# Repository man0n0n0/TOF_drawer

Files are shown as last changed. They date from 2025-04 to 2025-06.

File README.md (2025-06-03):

# configuration mode notice 

- turn off the device by unplugging it
- **keep** the config button pressed
- plug the device
  (while started you can release the button)
- connect on the wifi hotspot
  SSID : **"drawer-config"**
  PASSWORD : **"admin123"**
- while connected go to **192.168.4.1**
- modify values and **Save settings**
- the drawer should automatically restart in "main mode" with updated values

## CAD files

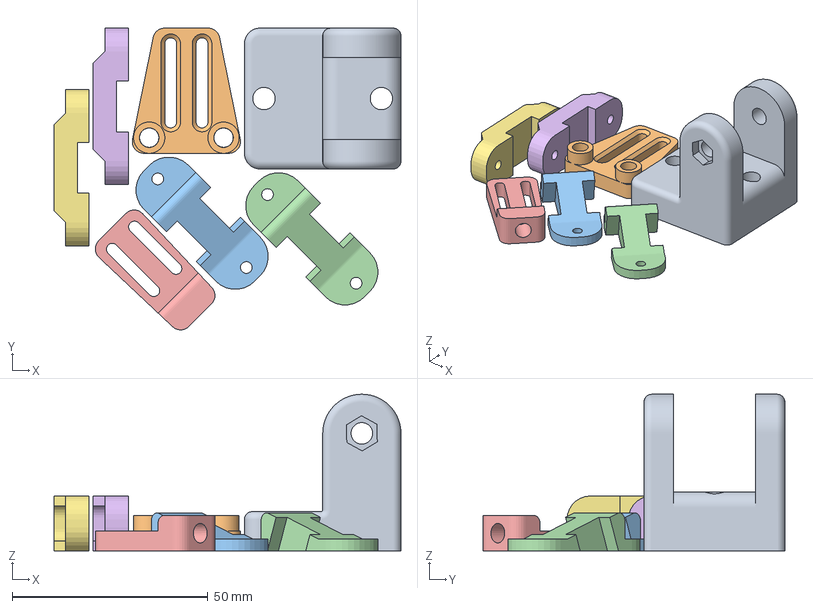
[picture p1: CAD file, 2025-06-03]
hardware/00fullparts.3mf
88.7 x 77.1 x 40.0 mm
04pulley_holder_screw-BodyPocket002.stl
01end_switch-Body.stl
ld2410_angledholder-Body003Chamfer.stl x 2
end_switch_compensator-Body.stl
02GT5belttensionner-Body.stl x 2

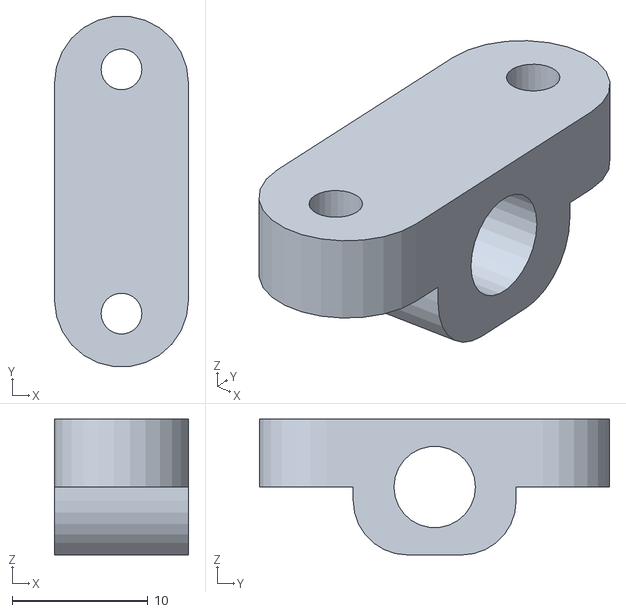
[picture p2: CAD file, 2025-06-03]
hardware/end_switch_compensator-Body.stl
9.86 x 25.8 x 10.0

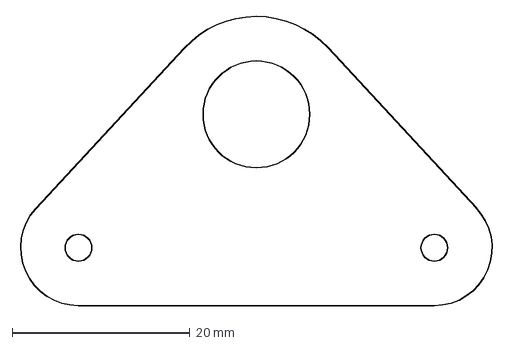
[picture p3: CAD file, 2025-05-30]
hardware/config_swtich_holder.dxf
54.0 x 32.5 mm

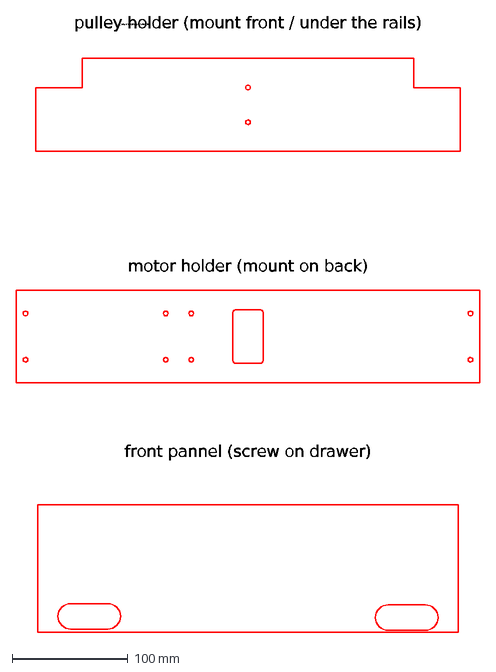
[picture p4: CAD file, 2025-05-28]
hardware/06cnc_cutting.dxf
pulley holder (front / under the rails)
pulley holder (mount front / under the rails)
motor holder (mount on back)
front pannel (screw on drawer)

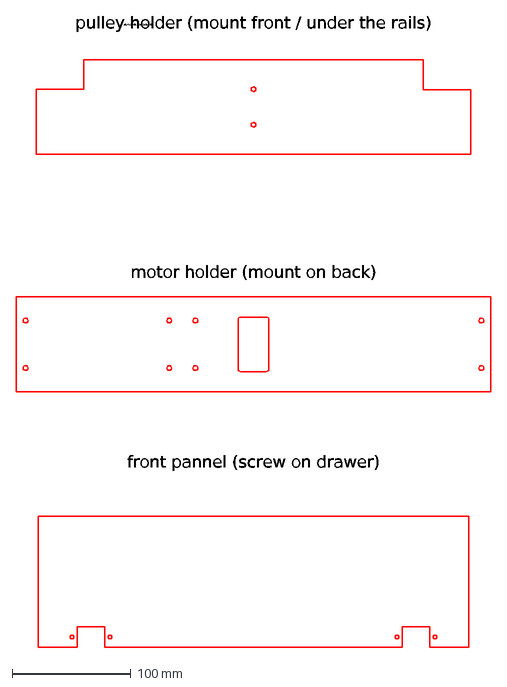
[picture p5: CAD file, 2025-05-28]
hardware/05cnc_cutting.dxf
pulley holder (front / under the rails)
pulley holder (mount front / under the rails)
motor holder (mount on back)
front pannel (screw on drawer)

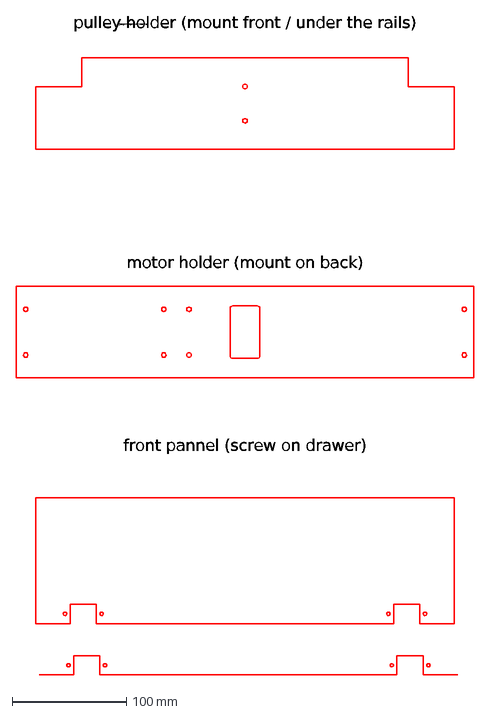
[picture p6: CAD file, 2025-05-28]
hardware/04cnc_cutting.dxf
pulley holder (front / under the rails)
pulley holder (mount front / under the rails)
motor holder (mount on back)
front pannel (screw on drawer)

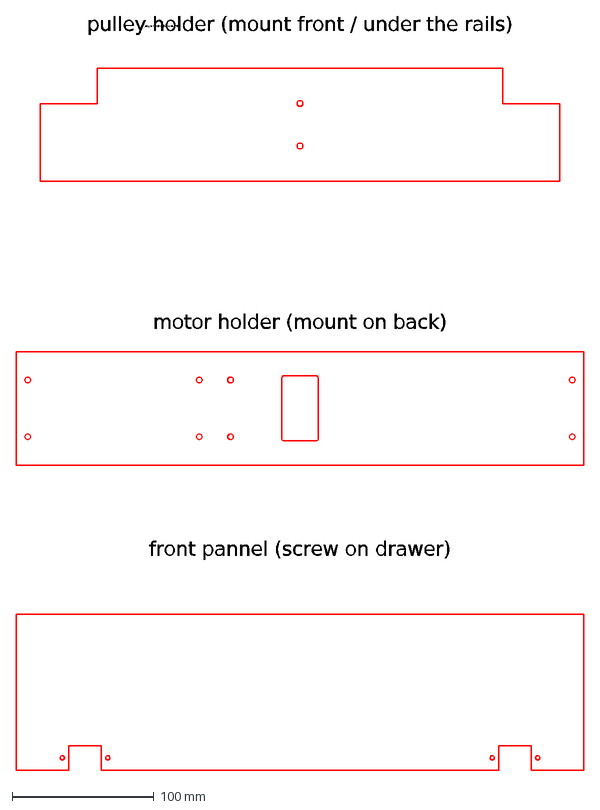
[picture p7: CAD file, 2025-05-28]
hardware/02cnc_cutting.dxf
pulley holder (front / under the rails)
pulley holder (mount front / under the rails)
motor holder (mount on back)
front pannel (screw on drawer)

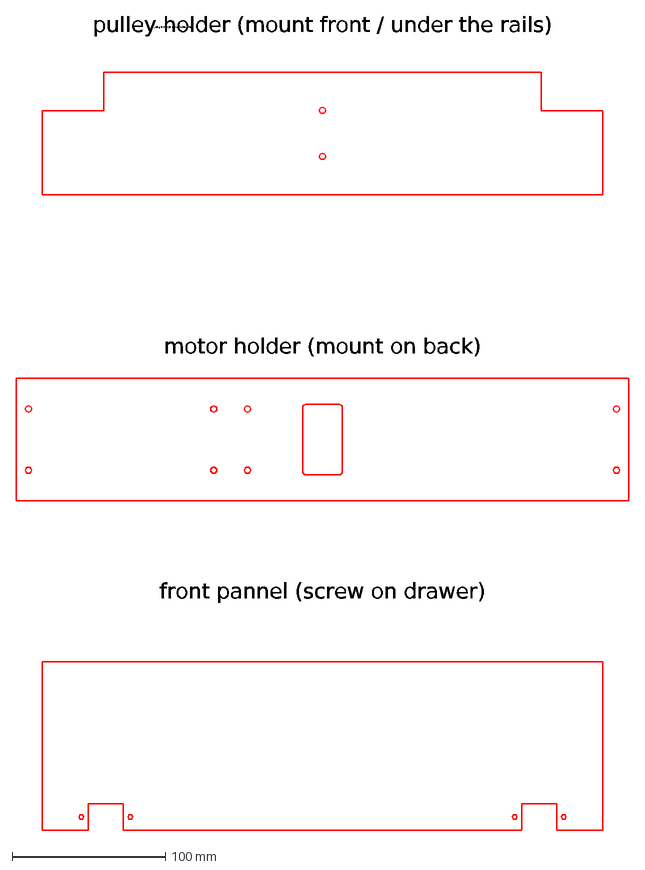
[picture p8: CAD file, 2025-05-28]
hardware/03cnc_cutting.dxf
pulley holder (front / under the rails)
pulley holder (mount front / under the rails)
motor holder (mount on back)
front pannel (screw on drawer)

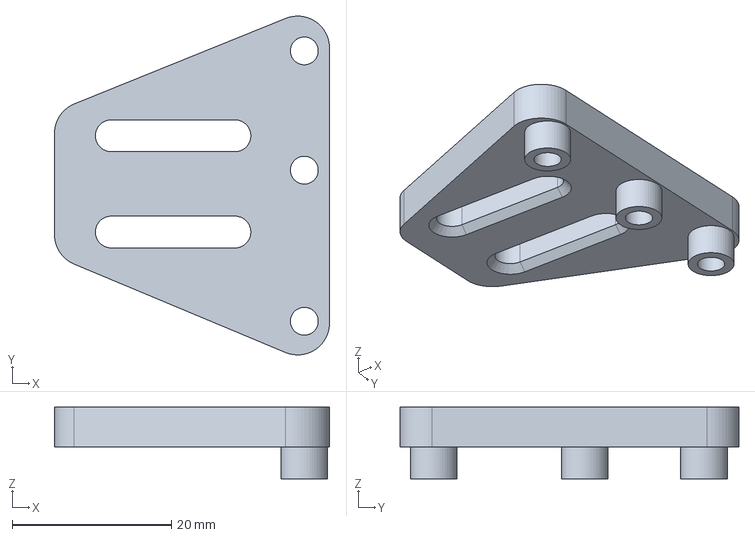
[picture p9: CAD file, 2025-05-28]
hardware/end_switch.FCStd
34.6 x 42.6 x 9.00 mm

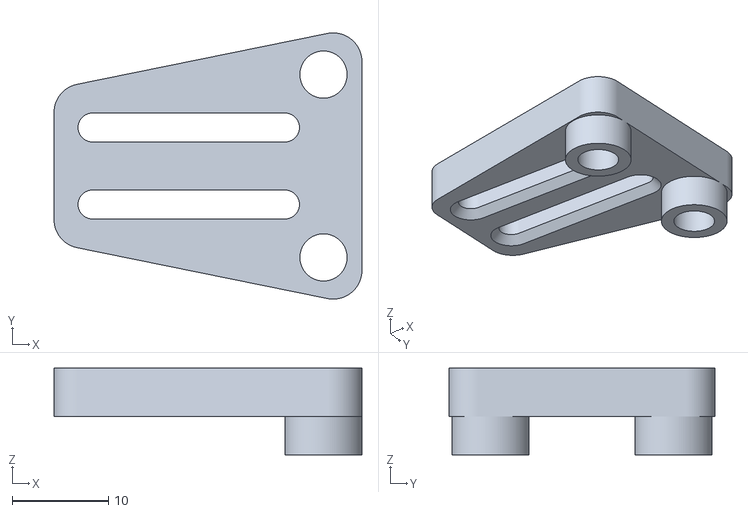
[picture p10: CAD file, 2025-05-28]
hardware/01end_switch-Body.stl
32.0 x 27.7 x 9.00

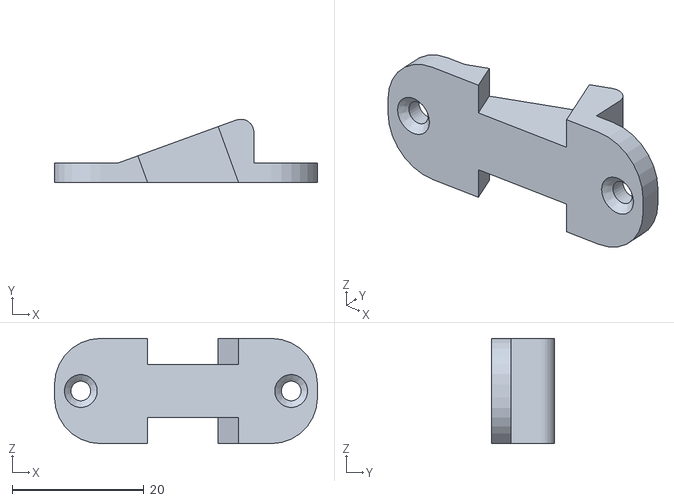
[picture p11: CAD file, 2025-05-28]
hardware/ld2410_angledholder-Body003Chamfer.stl
40.0 x 9.66 x 16.0

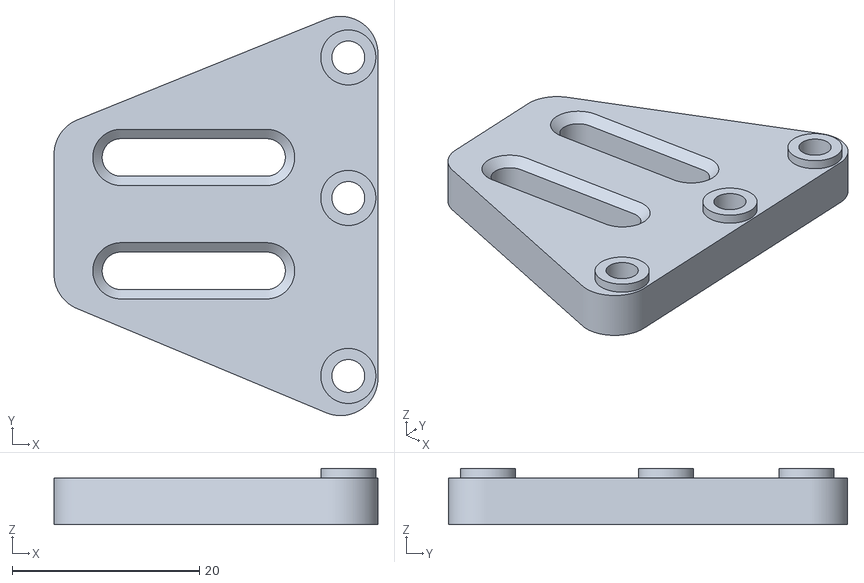
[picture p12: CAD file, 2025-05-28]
hardware/end_switch-BodyChamfer.stl
34.6 x 42.6 x 6.00

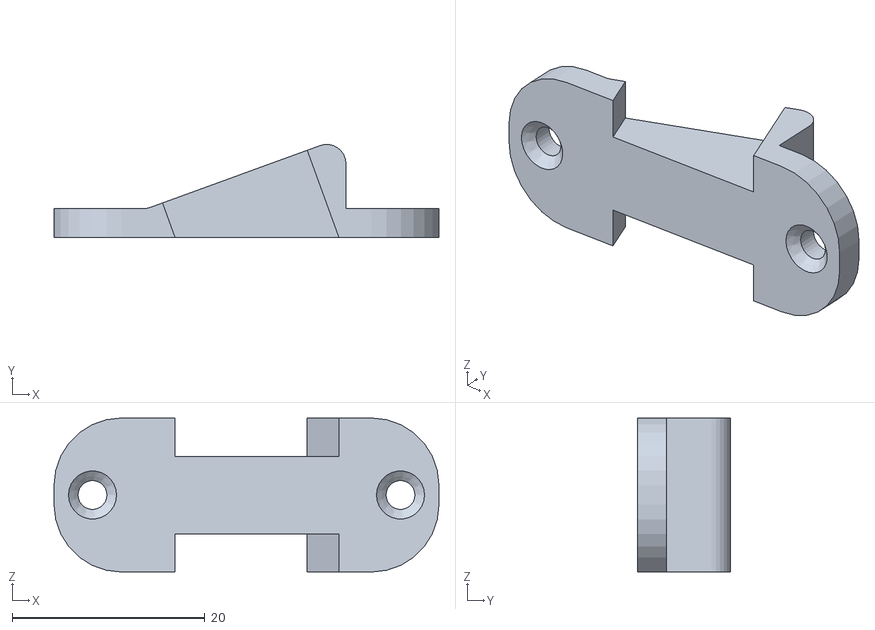
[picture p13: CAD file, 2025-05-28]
hardware/ld2410_angledholder-Body003.stl
40.0 x 9.66 x 16.0

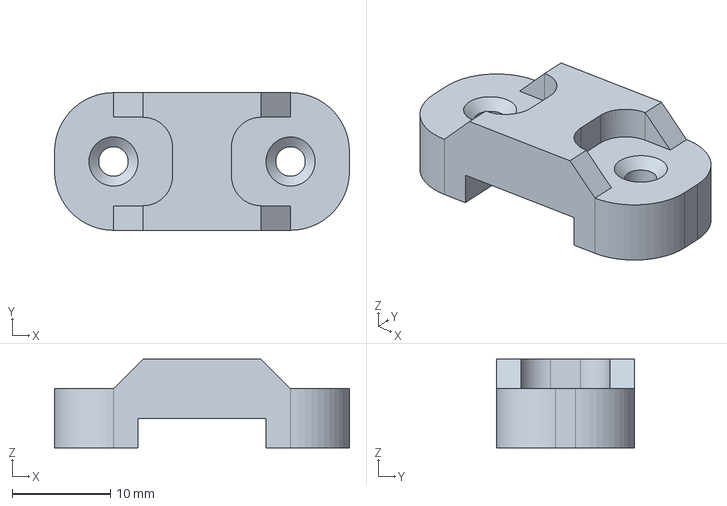
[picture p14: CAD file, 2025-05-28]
hardware/01GT5belttensionner.FCStd
30.0 x 14.0 x 9.00 mm

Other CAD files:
hardware/AB25_assembly.FCStd
hardware/end_switch_compensator.FCStd
hardware/00cnc_cutting.dxf
hardware/01GT5belttensionner-BodyChamfer.stl
hardware/00GT5belt_fix_m5insert.FCStd
hardware/00GT5belt_fix_m5insert.stl
hardware/00GT5belt_tensioner_fixedpart_m5insert-Body.stl
hardware/00GT5belt_tensioner_fixedpart_m5insert.FCStd
hardware/00GT5belt_tensioner_m5insert-BodyPocket001.stl
hardware/00GT5belt_tensioner_m5insert.FCStd
hardware/00_pulley_holder_meutriere.FCStd
hardware/00_pulley_holder_screw.FCStd
hardware/00_pulley_holder_screw.stl
hardware/00end_switch-Body.dxf
hardware/00end_switch-Body.stl
hardware/00nema23_bracket_offsettirroir-BodyChamfer001.stl
hardware/00nema23_bracket_offsettirroir.FCStd
hardware/00pcb_mount.stl
hardware/01GT5belt_fix_m5insert-Body.stl
hardware/01GT5belt_fix_m5insert.FCStd
hardware/01_pulley_holder_screw-Body.stl
hardware/01_pulley_holder_screw.FCStd
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

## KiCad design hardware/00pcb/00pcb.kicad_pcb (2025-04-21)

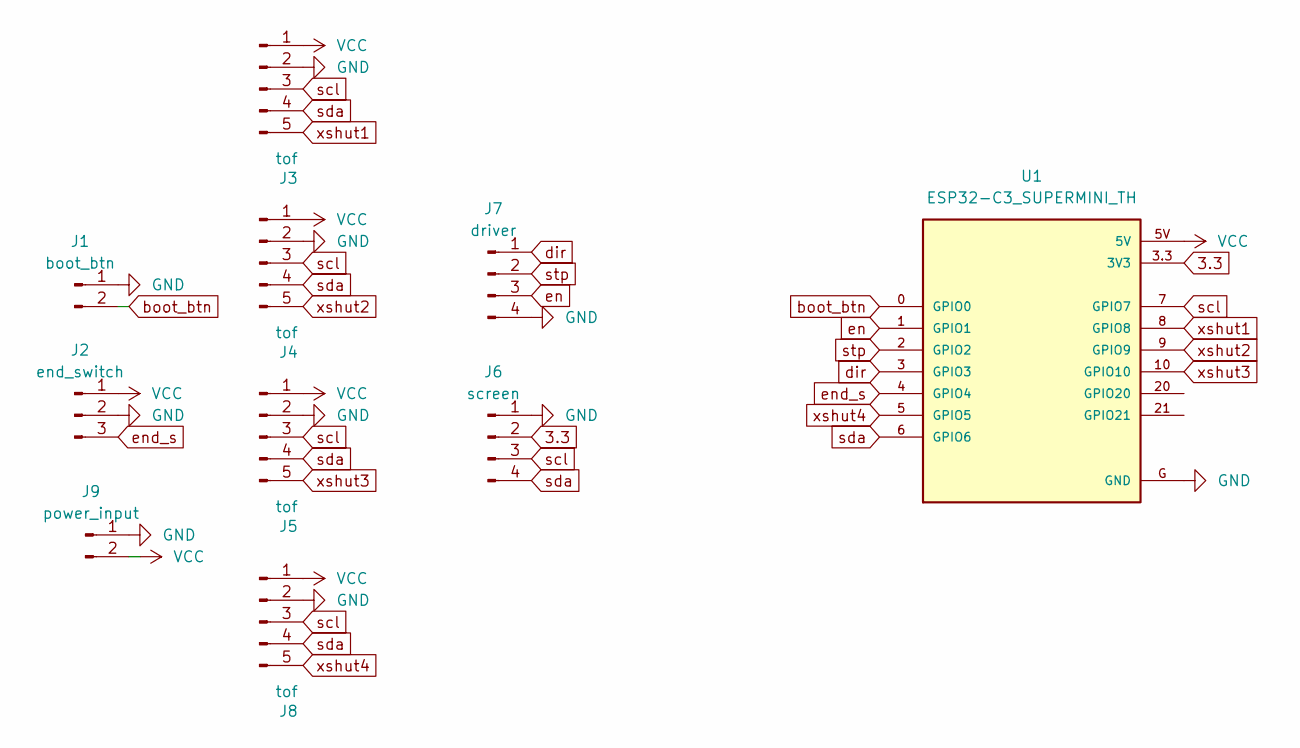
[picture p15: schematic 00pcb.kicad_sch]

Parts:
J1: boot_btn; PinHeader_1x02_P2.54mm_Vertical
J2: end_switch; PinHeader_1x03_P2.54mm_Vertical
J3, J4, J5, J8: tof; JST_XH_B5B-XH-A_1x05_P2.50mm_Vertical
J6: screen; PinHeader_1x04_P2.54mm_Vertical
J7: driver; JST_XH_B4B-XH-A_1x04_P2.50mm_Vertical
J9: power_input; PinHeader_1x02_P2.54mm_Vertical
U1: ESP32-C3_SUPERMINI_TH; MODULE_ESP32-C3_SUPERMINI

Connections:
3.3: J6.2, U1.3.3 (3V3)
GND: J1.1, J2.2, J3.2, J4.2, J5.2, J6.1, J7.4, J8.2, J9.1, U1.G (GND)
VCC: J2.1, J3.1, J4.1, J5.1, J8.1, J9.2, U1.5V
boot_btn: J1.2, U1.0 (GPIO0)
dir: J7.1, U1.3 (GPIO3)
en: J7.3, U1.1 (GPIO1)
end_s: J2.3, U1.4 (GPIO4)
scl: J3.3, J4.3, J5.3, J6.3, J8.3, U1.7 (GPIO7)
sda: J3.4, J4.4, J5.4, J6.4, J8.4, U1.6 (GPIO6)
stp: J7.2, U1.2 (GPIO2)
xshut1: J3.5, U1.8 (GPIO8)
xshut2: J4.5, U1.9 (GPIO9)
xshut3: J5.5, U1.10 (GPIO10)
xshut4: J8.5, U1.5 (GPIO5)

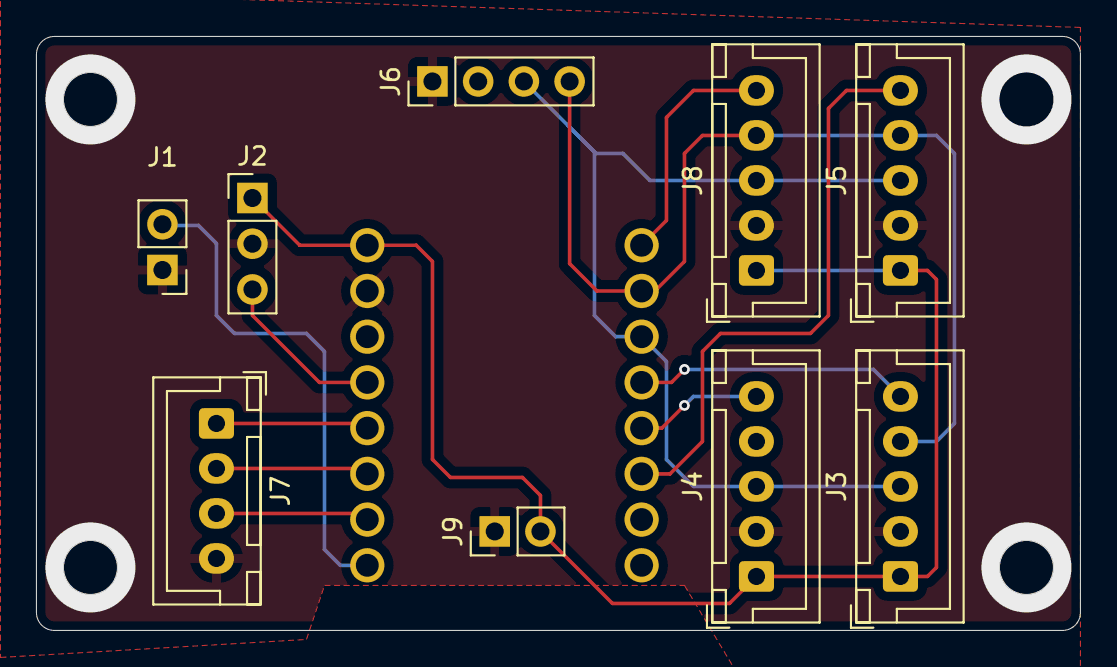
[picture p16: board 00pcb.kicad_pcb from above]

Board: 2 copper layers, 58.0 x 33.0 mm, 10 parts (1 on the bottom side), 14 nets.

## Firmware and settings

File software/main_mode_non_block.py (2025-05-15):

from machine import UART, Pin, I2C
import json
import asyncio
from ssd1306 import SSD1306_I2C
from time import sleep_ms, ticks_ms, ticks_diff
from DM332T import DM332TStepper
from ld2410 import LD2410

# Constants
CONFIG_FILE = 'config.json'
DEFAULT_CONFIG = {
    "d_threshold": 500,
    "back_speed": 8100,
    "forw_speed": 1100,
    "wait_inside": 3000,
    "steps_per_rev": 3200,
    "step_per_mm": 25.6,
    "d_out": 220,
    "homing_speed": 500
}

# Global variables for state
r_d = 0
human = True
radar_running = True
last_display_update = 0

def load_config():
    """Load configuration from JSON file or use defaults"""
    try:
        with open(CONFIG_FILE, 'r') as f:
            return json.loads(f.read())
    except:
        # If file doesn't exist or has errors, create it with defaults
        with open(CONFIG_FILE, 'w') as f:
            f.write(json.dumps(DEFAULT_CONFIG))
        return DEFAULT_CONFIG

def display_msg(display, msg):
    """Display message on OLED screen"""
    display.fill(0)
    display.text("AB_DRAWER", 0, 0, 1)
    y = 12
    for line in msg.split('\n'):
        display.text(line, 0, y, 1)
        y += 10
    display.show()

# This class will handle low-level movement for the stepper
class NonBlockingStepper:
    def __init__(self, stepper):
        self.stepper = stepper
        self.is_moving = False
        self.is_homing = False
        self.target_mm = 0
        self.current_mm = 0
        self.step_delay_ms = 1
        self.last_step_time = 0
        self.homing_switch = None
        self.homing_speed = 500
        
    async def move_to_mm_non_blocking(self, mm_position, speed):
        """Start moving stepper to position in mm without blocking"""
        self.stepper.enable()
        self.stepper.set_speed(speed)
        self.target_mm = mm_position
        self.is_moving = True
        self.is_homing = False
        # Return immediately, movement will be handled in update()
    
    async def home_non_blocking(self, end_switch, speed):
        """Start homing stepper without blocking"""
        self.stepper.enable()
        self.stepper.set_speed(speed)
        self.homing_switch = end_switch
        self.is_homing = True
        self.is_moving = True
        # Return immediately, homing will be handled in update()
    
    async def update(self):
        """Update stepper position - call this frequently"""
        if not self.is_moving:
            return
            
        current_time = ticks_ms()
        
        # Only move if enough time has passed since last step
        if ticks_diff(current_time, self.last_step_time) < self.step_delay_ms:
            return
            
        self.last_step_time = current_time
        
        # Handle homing
        if self.is_homing:
            # If home switch is pressed, homing is complete
            if not self.homing_switch.value():
                self.is_homing = False
                self.is_moving = False
                self.current_mm = 0
                self.stepper.position = 0  # Reset position counter
                print("Homing complete")
                return
                
            # Step toward home
            self.stepper.set_dir(False)  # Direction toward home switch
            self.stepper.step()  # Take one step
            return
            
        # Handle regular movement
        # Calculate current position in mm
        self.current_mm = self.stepper.position / self.stepper.steps_per_mm
        
        # Determine direction based on target
        if abs(self.current_mm - self.target_mm) < 0.1:
            # Target reached
            self.is_moving = False
            print(f"Target reached: {self.current_mm}mm")
            return
            
        # Determine direction and step
        if self.current_mm < self.target_mm:
            # Move away from home
            self.stepper.move_mm(0.1)  # Move a tiny bit forward
        else:
            # Move toward home
            self.stepper.move_mm(-0.1)  # Move a tiny bit backward

async def read_radar():
    """Non-blocking radar reading coroutine"""
    global r_d, human
    
    # Initialize radar and UART
    uart = UART(1, baudrate=256000)
    uart.init(tx=Pin(10), rx=Pin(3))
    r = LD2410()
    
    # Load configuration to get threshold
    config = load_config()
    threshold = config["d_threshold"]
    
    while True:
        # Read radar data
        r.begin(uart)
        r.read()

        # Check if targets are detected
        if r.stationary_target_detected():
            r_d = r.stationary_target_distance() * 10
            if r_d < threshold:
                human = True
            else:
                human = False
            print(f"Radar: {r_d}mm, Human: {'Yes' if human else 'No'}")
        else:
            # No target detected
            human = False
            
        # Small delay to yield to other tasks
        await asyncio.sleep_ms(50)

async def drawer_controller():
    """Non-blocking drawer control coroutine"""
    global human, r_d, last_display_update
    
    # Initialize hardware
    i2c = I2C(0, sda=Pin(5), scl=Pin(6))
    display = SSD1306_I2C(70, 40, i2c)
    
    # Load configuration
    config = load_config()
    
    # Initialize stepper motor with DM332T driver
    STEP_PIN = 0     # GPIO pin connected to STEP input on DM332T
    DIR_PIN = 2      # GPIO pin connected to DIR input on DM332T  
    ENABLE_PIN = 7   # GPIO pin connected to ENA input on DM332T
    HOME_SWITCH_PIN = 8  # GPIO pin connected to home switch
    
    # Create stepper object
    s = DM332TStepper(
        step_pin=STEP_PIN,
        dir_pin=DIR_PIN,
        enable_pin=ENABLE_PIN,
        invert_dir=True,
        steps_per_rev=config["steps_per_rev"],
        steps_per_mm=config["step_per_mm"]
    )
    
    # Create our non-blocking wrapper
    nb_stepper = NonBlockingStepper(s)
    
    # End switch declaration
    end_s = Pin(HOME_SWITCH_PIN, Pin.IN, Pin.PULL_UP)
    
    # Configure stepper acceleration
    s.set_acceleration(60000)  # steps/second²
    s.set_deceleration(30000)  # steps/second²
    s.enable_acceleration()
    s.enable()
    
    # Extract configuration parameters
    d_threshold = config["d_threshold"]
    back_speed = config["back_speed"] 
    forw_speed = config["forw_speed"]
    wait_inside = config["wait_inside"]
    d_out = config["d_out"]
    homing_speed = config["homing_speed"]
    
    # Home the drawer mechanism
    display_msg(display, "Homing...")
    await nb_stepper.home_non_blocking(end_s, homing_speed)
    
    # Wait for homing to complete, while still calling update
    while nb_stepper.is_homing:
        await nb_stepper.update()
        await asyncio.sleep_ms(1)  # Yield to other tasks
    
    display_msg(display, "HOMED!\nStarting...")
    
    # Track drawer state
    drawer_closed = True
    drawer_target_state = True  # True = closed, False = open
    last_state_change = ticks_ms()
    movement_start_time = ticks_ms()
    last_display_update = ticks_ms()
    
    while True:
        current_time = ticks_ms()
        
        # Update the stepper position
        await nb_stepper.update()
        
        # Check if movement just finished
        if nb_stepper.is_moving == False and drawer_target_state != drawer_closed:
            drawer_closed = drawer_target_state
            s.disable()  # Disable motor to save power
            print(f"Movement complete. Now {'closed' if drawer_closed else 'open'}")
        
        # State machine for drawer operation
        cooldown_expired = ticks_diff(current_time, last_state_change) > 500
        
        if human and not drawer_closed and not nb_stepper.is_moving and cooldown_expired:
            # CLOSE DRAWER
            display_msg(display, f"Closing drawer\nDistance: {r_d}mm")
            s.enable()
            await nb_stepper.home_non_blocking(end_s, homing_speed)
            drawer_target_state = True
            last_state_change = current_time
            
        elif not human and drawer_closed and not nb_stepper.is_moving and cooldown_expired:
            # OPEN DRAWER
            display_msg(display, f"Opening drawer\nDistance: {r_d}mm")
            s.enable()
            await nb_stepper.move_to_mm_non_blocking(d_out, forw_speed)
            drawer_target_state = False
            last_state_change = current_time
            
        # Update display periodically
        if ticks_diff(current_time, last_display_update) > 200:  # Update every 200ms
            state = "Closed" if drawer_closed else "Open"
            moving = " (moving)" if nb_stepper.is_moving else ""
            target = " -> " + ("Close" if drawer_target_state else "Open") if drawer_target_state != drawer_closed else ""
            display_msg(display, f"State: {state}{moving}{target}\nDistance: {r_d}mm\nHuman: {'Yes' if human else 'No'}")
            last_display_update = current_time
        
        # Small delay to yield to other tasks
        await asyncio.sleep_ms(5)

async def main():
    """Main entry point for the application"""
    # Create the two main tasks
    radar_task = asyncio.create_task(read_radar())
    drawer_task = asyncio.create_task(drawer_controller())
    
    # Run both tasks concurrently, without one waiting for the other
    await asyncio.gather(radar_task, drawer_task)

# Run the main function
if __name__ == "__main__":
    try:
        asyncio.run(main())
    except KeyboardInterrupt:
        print("Program terminated by user")
    finally:
        radar_running = False  # Stop radar task

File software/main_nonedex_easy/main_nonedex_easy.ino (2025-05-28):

#include <WiFi.h>
#include <WebServer.h>
#include <Preferences.h>
#include <AccelStepper.h>
#include <ld2410.h>
#include <ArduinoJson.h>
#include <SPIFFS.h>

// Stepper specific
#define STEP_PIN 33     
#define DIR_PIN 25
#define EN_PIN 26                                                                                                                                                                                                                                                                                                                                                                                                                                                                                                                                      
#define STEP_PER_MM 25.6  // 25.6 steps per mm

#define MONITOR_SERIAL Serial

// RADAR 1
#define RADAR1_SERIAL Serial1
#define RADAR1_RX_PIN 32
#define RADAR1_TX_PIN 12

// RADAR 2
#define RADAR2_SERIAL Serial2
#define RADAR2_RX_PIN 14
#define RADAR2_TX_PIN 27

// Button pin configuration
#define CONFIG_BUTTON_PIN 17  
#define ENDSWITCH_PIN 15

// Drawer specific
#define D_OUT 180
// Access Point credentials
const char* ap_ssid = "ESP32_Control";
const char* ap_password = "12345678";

// Variables to be modified via web interface
int D_THRESHOLD = 300;    // Default: 300cm
int BACK_SPEED = 8000;     // Default: 8000 steps/sec
int FORW_SPEED = 1000;     // Default: 1000 steps/sec
int WAIT_INSIDE = 3000;    // Default: 3000ms

// Operation mode flag
bool configMode = false;

// Create webserver on port 80
WebServer server(80);

// Preferences object for persistent storage
Preferences preferences;

// Create the stepper instance
AccelStepper stepper(AccelStepper::DRIVER, STEP_PIN, DIR_PIN);

// radar declaration
ld2410 radar1;
ld2410 radar2;

uint32_t r1_lastreading = 0;
volatile int radar1_d;
bool radar1Connected = false;

uint32_t r2_lastreading = 0;
volatile int radar2_d;
bool radar2Connected = false;
   
uint32_t last_movement = 0;
volatile int human_d;

bool isHomed = false;
bool IsOpen = true; //so that it engage homing at start

/*##################################################################################
SETUP LOOP
##################################################################################*/

void setup() {
  // Start serial for debugging
  // Initialize serial communication
  MONITOR_SERIAL.begin(115200); //Feedback over Serial Monitor
  MONITOR_SERIAL.println("Starting setup...");
  
  // Initialize button pin && endswitch
  pinMode(CONFIG_BUTTON_PIN, INPUT_PULLUP);
  pinMode(ENDSWITCH_PIN, INPUT_PULLUP);
  
  // Load saved values (needed in both modes)
  loadSavedValues();
  
  // Check if button is pressed at startup
  if (digitalRead(CONFIG_BUTTON_PIN) == LOW) {
    MONITOR_SERIAL.println("Config button pressed - entering configuration mode");
    configMode = true;
    
    // Set up ESP32 as an Access Point
    WiFi.mode(WIFI_AP);
    WiFi.softAP(ap_ssid, ap_password);
    
    // Define server endpoints
    server.on("/", HTTP_GET, handleRoot);
    server.on("/", HTTP_POST, handleFormSubmission);
    
    // Start the server
    server.begin();
  } else {
    configMode = false;

    // Configure the stepper
    stepper.setPinsInverted(true);
    stepper.setMaxSpeed(15000);
    stepper.setAcceleration(10000);
    pinMode(EN_PIN, OUTPUT);
    digitalWrite(EN_PIN, LOW); 
  
    //radar1 initialisation
    RADAR1_SERIAL.begin(256000, SERIAL_8N1, RADAR1_RX_PIN, RADAR1_TX_PIN); //UART for monitoring the radar
    delay(500);
   
    if(radar1.begin(RADAR1_SERIAL))
    {
      MONITOR_SERIAL.println(F("OK"));
    }
    else
    {
      MONITOR_SERIAL.println(F("not connected"));
    }
    
    //radar2 initialisation
    RADAR2_SERIAL.begin(256000, SERIAL_8N1, RADAR2_RX_PIN, RADAR2_TX_PIN); //UART for monitoring the radar
    delay(500);
   
    if(radar2.begin(RADAR2_SERIAL))
    {
      MONITOR_SERIAL.println(F("OK"));
    }
    else
    {
      MONITOR_SERIAL.println(F("not connected"));
    }
    
    Serial.println("Setup complete");
   
  }
}

/*##################################################################################
MAIN LOOP
##################################################################################*/

void loop() {
  if (configMode) 
  {
    // Handle client requests in configuration mode
    server.handleClient();
  } 
  else 
  {
    // Radar1 mesurement logic
    radar1.read();
    
    if(radar1.isConnected() && millis() - r1_lastreading > 20)  //Report every 20ms
    {
      r1_lastreading = millis();                                            

      radar1_d = radar1.stationaryTargetDistance();
      MONITOR_SERIAL.println(radar1_d);

    }
  
    // Radar2 mesurement logic
    radar2.read();
    
    if(radar2.isConnected() && millis() - r2_lastreading > 20)  //Report every 20ms
    {
      r2_lastreading = millis();

      radar2_d = radar2.stationaryTargetDistance();
      MONITOR_SERIAL.println(radar2_d);
     
    }
  
    // Presence value math operation
    human_d = min(radar1_d,radar2_d);
    //MONITOR_SERIAL.println(human_d);
    //MONITOR_SERIAL.println(D_THRESHOLD);
    
    if (human_d < D_THRESHOLD && IsOpen) {
      digitalWrite(EN_PIN, LOW); //enable stepper
      
      // Move BACKWARD 
      stepper.setMaxSpeed(BACK_SPEED);
      stepper.moveTo(10 * STEP_PER_MM);
      stepper.runToPosition(); // (blocking)

      if (!isHomed)
      {      
        while (digitalRead(ENDSWITCH_PIN)) 
        {    
          digitalWrite(DIR_PIN, HIGH);      // (HIGH = anti-clockwise / LOW = clockwise)
          digitalWrite(STEP_PIN, HIGH);
          delay(5);                         // Delay to slow down speed of Stepper
          digitalWrite(STEP_PIN, LOW);
          delay(5);    
        } 
        
        stepper.setCurrentPosition(0);
        stepper.moveTo(1 * STEP_PER_MM);
        stepper.runToPosition(); // (blocking)
        
        delay(WAIT_INSIDE);
        //MONITOR_SERIAL.println("homed ! wainting inside");
        radar1_d=0;
        radar2_d=0;
        digitalWrite(EN_PIN, HIGH); //disable stepper
        isHomed = true;
        IsOpen = false;
      }
    } 
    
    else if ( human_d > D_THRESHOLD && !IsOpen )
    {
      //MOVE FORWARD
      digitalWrite(EN_PIN, LOW); //enable stepper
      isHomed = false; // homing management
      IsOpen = true;
      
      // Return to starting position (0mm)
      stepper.setMaxSpeed(FORW_SPEED);
      stepper.moveTo(D_OUT * STEP_PER_MM);

      //BLOCKING
      stepper.runToPosition(); // (blocking)

      delay(2000);

      //NON BLOCKING  
//      // Disabling management
//      if (stepper.currentPosition() == D_OUT)
//      {
//        digitalWrite(EN_PIN, HIGH); //disable stepper
//      }
    }
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

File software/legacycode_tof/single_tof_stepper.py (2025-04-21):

import os
import vl53l0x
from machine import Pin, I2C
from ssd1306 import SSD1306_I2C  
from time import sleep_ms
from stepper import Stepper

'''piece variable'''
steps_per_rev = 3200
step_per_mm = 25.6 #https://blog.prusa3d.com/calculator_3416/
d_threshold = 1000 #minimal distance for deteciton(mm)
d_out = 220 #distance from homing point (mm
back_speed = 11100 #vitesse de retractation du tirroir (stp/sec)
forw_speed = 1100 #vitesse de sortie du tirroir (step/sec)
wait_inside = 3333 # waiting time after the drawer got inside (mm)

def homing(): 
    s.speed(100) 
    s.free_run(-1) #move forward

    while end_s.value() == 1:
        pass
    
    display.text(f"homed",18, 30, 1)
    display.show()
    s.stop() #stop as soon as the switch is triggered
    s.overwrite_pos(0) #set position as 0 point
    s.target(0) #set the target to the same value to avoid unwanted movement

'''init'''
i2c = I2C(0, sda=Pin(5), scl=Pin(6))

'''--tof'''
vl1xshut = Pin(10, Pin.OUT)#2
# vl2xshut = Pin(15, Pin.OUT)
# vl3xshut = Pin(16, Pin.OUT)
xshut = [
    vl1xshut,
#     vl2xshut,
#     vl3xshut,
]
vl53 = []
for index , power_pin in enumerate(xshut):
    power_pin.value(1)
    vl53.insert(index , vl53l0x.VL53L0X(i2c))  
    if index < len(xshut) - 1:
        vl53[index].set_address(index + 0x30)
        
'''--embeded display'''
display = SSD1306_I2C(70, 40, i2c)

'''--stepper'''
s = Stepper(0,2,1,steps_per_rev=steps_per_rev) #stp,dir,en
end_s = Pin(3, Pin.IN, Pin.PULL_UP)

homing()

'''execution'''
while True :
    d = min(vl53[0].range, 6666, 6666) 
    display.fill(0)    
    display.text(f"{d}",23, 23, 1)
    
    if d < d_threshold :

        for vel in range(100,back_speed,100):
            s.speed(vel) 
            s.target(10*step_per_mm) # 3mm from home
            sleep_ms(5)
        sleep_ms(500)

        homing()

        sleep_ms(wait_inside - 500)

    else :
#         display.fill_rect(27, 0, 16, 16, 1)        
#         display.fill_rect(28, 1, 14, 14, 0)        
#         display.vline(31, 4, 11, 1)                
#         display.vline(35, 1, 11, 1)                 
#         display.vline(38, 4, 11, 1)                
#         display.fill_rect(40, 12, 1, 2, 1)          
#         display.show()

        s.track_target() #start stepper again

        s.speed(forw_speed)
        s.target(d_out*step_per_mm)

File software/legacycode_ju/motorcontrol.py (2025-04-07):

import utime
import machine


class motorControl :
    def __init__(self,pin):
        self.pwm = machine.PWM(machine.Pin(pin))
        self.target_speed = 0
        self.current_speed = 0
        self.step_increment = 1
        self.ramp_time = 0
        self.direction = 1
        self.delta = 0 
        self.pwm.duty(self.current_speed)
        self.last_call_time = utime.ticks_us()
        
        
    def set_target_speed(self, speed, time_to_ramp=None, step_increment=1):
        self.target_speed = speed
        self.current_speed = self.pwm.duty()
        self.delta = self.current_speed  - speed
        self.direction = 1 if self.delta < 0  else -1
        self.step_increment = step_increment
        self.time_to_ramp = time_to_ramp*1000000 or 0
        self.steps_qty = abs(self.delta / self.step_increment)
        if self.steps_qty < 1:
            self.steps_qty = 1
        self.steps_timming = self.time_to_ramp / self.steps_qty

    
    def update_speed(self):
        current_time = utime.ticks_us()
        self.current_speed  = self.pwm.duty()
        time_elapsed = utime.ticks_diff(current_time, self.last_call_time)
        steps = int((time_elapsed / self.time_to_ramp) / self.step_increment) + 1
        #print(".")

        if  steps > 0 and time_elapsed > self.steps_timming:
            self.current_speed += self.direction * self.step_increment * steps
            self.current_speed = max(0, min(1023, self.current_speed))

            
            if self.direction == 1 and self.current_speed >= self.target_speed:
                self.pwm.duty(self.target_speed)
                return True
            elif self.direction == -1 and self.current_speed <= self.target_speed:
                self.pwm.duty(self.target_speed)
                return True
            
            self.pwm.duty(self.current_speed)
#             print(self.pwm.duty())
            self.last_call_time = current_time

        return False

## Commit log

2025-04-02 added pulley bracket
    [00_pulley_holder_meutriere.FCStd, 00_pulley_holder_screw.FCStd, 00_pulley_holder_screw.stl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]
2025-04-03 added hrdwr elements
    [00GT5belt_fix_m5insert.FCStd, 00GT5belt_fix_m5insert.stl, 00_pulley_holder_screw.FCStd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]
2025-04-04 new addition
    [00GT5belt_fix_m5insert.FCStd, 00GT5belt_fix_m5insert.stl, 00GT5belt_tensioner_fixedpart_m5insert-Body.stl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]
2025-04-07 pulley holder edit + new code on construction
    [01_pulley_holder_screw-Body.stl, 01_pulley_holder_screw.FCStd, derivation_box-Body.stl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]
2025-04-08 boot led for c3 + html
2025-04-09 added pcb
    [00pcb-B_Cu.gbr, 00pcb-B_Mask.gbr, 00pcb-B_Paste.gbp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]
2025-04-14 new driver + 3 tof
2025-04-21 radme + pcb
    [00pcb.kicad_pcb]
2025-04-23 edited library and print example (claudio)
2025-04-23 TODO:fix timing + uart maangement
    [main.py]
2025-04-24 threading of uart radar (claude edit)
2025-04-24 config logic edition + main threaded merged
2025-04-28 new lib + test case (claude)
2025-05-14 hardawre din rail + claude edit for new dm332t lib
    [00pcb_mount.stl, pcb_mount.FCStd]
2025-05-15 added track mm , enhanced dm332t lib, enhanced acceleration management
    working main code
    [ld2410_magnetholder-BodyPad.stl, ld2410_magnetholder-BodySketch.stl, ld2410_magnetholder.FCStd]
2025-05-17 working main mode (with latency) + dm332t lib withotu accel profile
    [dmt332t_mount-Body.stl, dmt332t_mount-BodyMirrored.stl, dmt332t_mount.FCStd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]
2025-05-19 dual uart using ( 2 radar module) + dual core with regular esp32
    [pcb_mount.FCStd]
2025-05-20 hardawre (sensor bracket) + optimisation in nonedex code
    [ld2410_magnetholder-Body.stl, ld2410_magnetholder-Body003.stl, ld2410_magnetholder.FCStd]
2025-05-20 using previous stepper driver (software)
2025-05-21 arduino version : faster process
    [dmt332t_mount.FCStd, driver_mount-BodyMirrored.stl, motor_data.json]
2025-05-22 d_out value + hardware
    [01GT5belttensionner.FCStd]
2025-05-28 hardware rewrok
    [00cnc_cutting.dxf, 00fullparts.3mf, 01GT5belttensionner-BodyChamfer.stl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]
2025-05-28 hardware + blocking out drawer
    [02cnc_cutting.dxf, 02pulley_holder_screw-Body.stl, 02pulley_holder_screw-BodyPocket002.stl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]
2025-05-28 gpio code !!
    [06cnc_cutting.dxf]
2025-06-03 last minute edit
    [00fullparts.3mf, end_switch_compensator-Body.stl, end_switch_compensator.FCStd]
